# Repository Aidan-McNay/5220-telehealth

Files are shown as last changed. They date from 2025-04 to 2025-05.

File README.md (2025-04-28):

# 5220-telehealth

A repository of our design for MAE 5220: Introduction to IoT, which
obtains blood pressure data from an Omron Evolv BP7000, and transmits
it over LoRaWAN to The Things Network (TTN).

Unlike the code for the rest of the class, our target platform is a
Raspberry Pi Pico W, so the build process is different than labs.

## Repository Structure

 - **CMakeLists.txt**: Instructions for our CMake-based build system
 - **app**: Target applications for the Pico W (each with a `main`)
 - **ble**: Source code for interfacing over BLE
 - **cmake**: Extra CMake utilities
 - **lorawan**: Source code for interfacing over LoRaWAN
 - **lorawan-library-for-pico**: A submodule library for using LoRaWAN on the Pico W
 - **pcb**: Our PCB design for the system
 - **pico_sdk_import.cmake**: CMake support for the Raspberry Pi SDK
 - **ui**: Source code for interfacing with physical UI devices (LEDs, buttons, etc.)
 - **utils**: Utility code used throughout the project

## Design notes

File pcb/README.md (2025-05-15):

# pcb

PCB design. The files marked with "original" show the PCB that we ordered with the PMOS footprint mismatch as described in our report.

The current layout and schematic contain the updated PCB with the mismatch fixed. To produce the current PCB, use corrected_gerberdrill.zip when ordering from JLBPCB.

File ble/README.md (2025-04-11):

# ble

Software for connecting to the OMRON blood pressure sensor over Bluetooth Low Energy (BLE)

*(Note: Much of the code was adapted from ECE 4760's example [here](https://vanhunteradams.com/Pico/BLE/GATT_Client.html))*

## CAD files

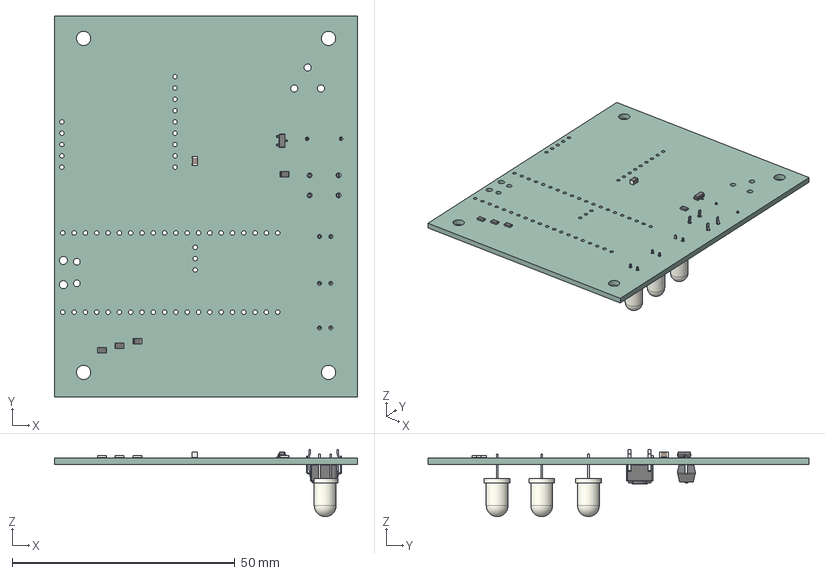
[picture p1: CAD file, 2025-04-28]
pcb/blood_pressure.step
68.0 x 85.5 x 15.1 mm
R_0805_2012Metric x 4
C_0805_2012Metric
SOT-23
LED_D5.0mm_Clear x 3
SW_PUSH_6mm
SW_DIP_SPSTx01_Slide_6.7x4.1mm_W7.62mm_P2.54mm_LowProfile
blood_pressure_PCB

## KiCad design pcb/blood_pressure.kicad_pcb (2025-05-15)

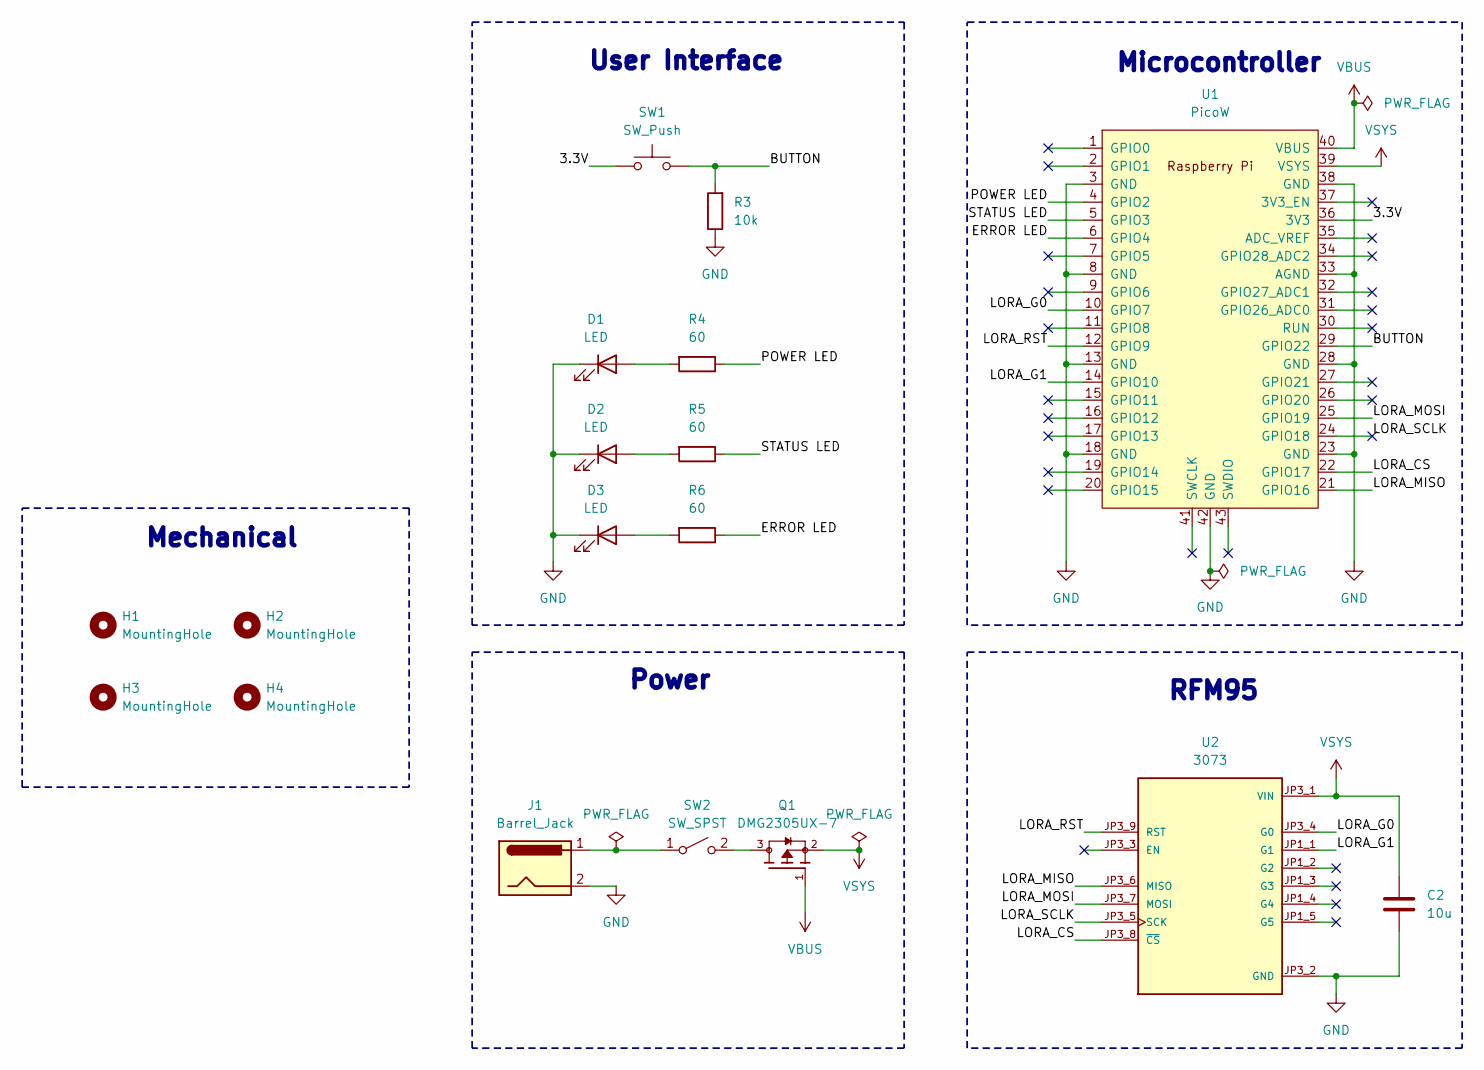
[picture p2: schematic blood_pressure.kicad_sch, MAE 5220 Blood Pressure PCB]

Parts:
C2: 10u; C_0805_2012Metric
D1, D2, D3: LED; LED_D5.0mm_Clear
H1, H2, H3, H4: MountingHole; MountingHole_3.2mm_M3
J1: Barrel_Jack; BarrelJack_CUI_PJ-102AH_Horizontal
Q1: DMG2305UX-7; SOT91P240X110-3N_DMG2305UX-7; PARTREV 09/2018
R3: 10k; R_0805_2012Metric
R4, R5, R6: 60; R_0805_2012Metric
SW1: SW_Push; SW_PUSH_6mm
SW2: SW_SPST; SW_DIP_SPSTx01_Slide_6.7x4.1mm_W7.62mm_P2.54mm_LowProfile
U1: PicoW; RPi_PicoW_SMD_TH
U2: 3073; rfm; PARTREV 2023-10-24

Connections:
/3.3V: SW1.1, U1.36 (3V3)
/BUTTON: R3.2, SW1.2, U1.29 (GPIO22)
/ERROR LED: R6.1, U1.6 (GPIO4)
/LORA_CS: U1.22 (GPIO17), U2.JP3_8 (~CS)
/LORA_G0: U1.10 (GPIO7), U2.JP3_4 (G0)
/LORA_G1: U1.14 (GPIO10), U2.JP1_1 (G1)
/LORA_MISO: U1.21 (GPIO16), U2.JP3_6 (MISO)
/LORA_MOSI: U1.25 (GPIO19), U2.JP3_7 (MOSI)
/LORA_RST: U1.12 (GPIO9), U2.JP3_9 (RST)
/LORA_SCLK: U1.24 (GPIO18), U2.JP3_5 (SCK)
/POWER LED: R4.1, U1.4 (GPIO2)
/STATUS LED: R5.1, U1.5 (GPIO3)
GND: C2.2, D1.1 (K), D2.1 (K), D3.1 (K), J1.2, R3.1, U1.3 (GND), U1.8 (GND), U1.13 (GND), U1.18 (GND), U1.23 (GND), U1.28 (GND), U1.33 (AGND), U1.38 (GND), U1.42 (GND), U2.JP3_2 (GND)
unnamed: D1.2 (A), R4.2
unnamed: D2.2 (A), R5.2
unnamed: D3.2 (A), R6.2
unnamed: J1.1, SW2.1 (A)
unnamed: Q1.3, SW2.2 (B)
VBUS: Q1.1, U1.40 (VBUS)
VSYS: C2.1, Q1.2, U1.39 (VSYS), U2.JP3_1 (VIN)

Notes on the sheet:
Microcontroller
RFM95
User Interface
Mechanical
Power

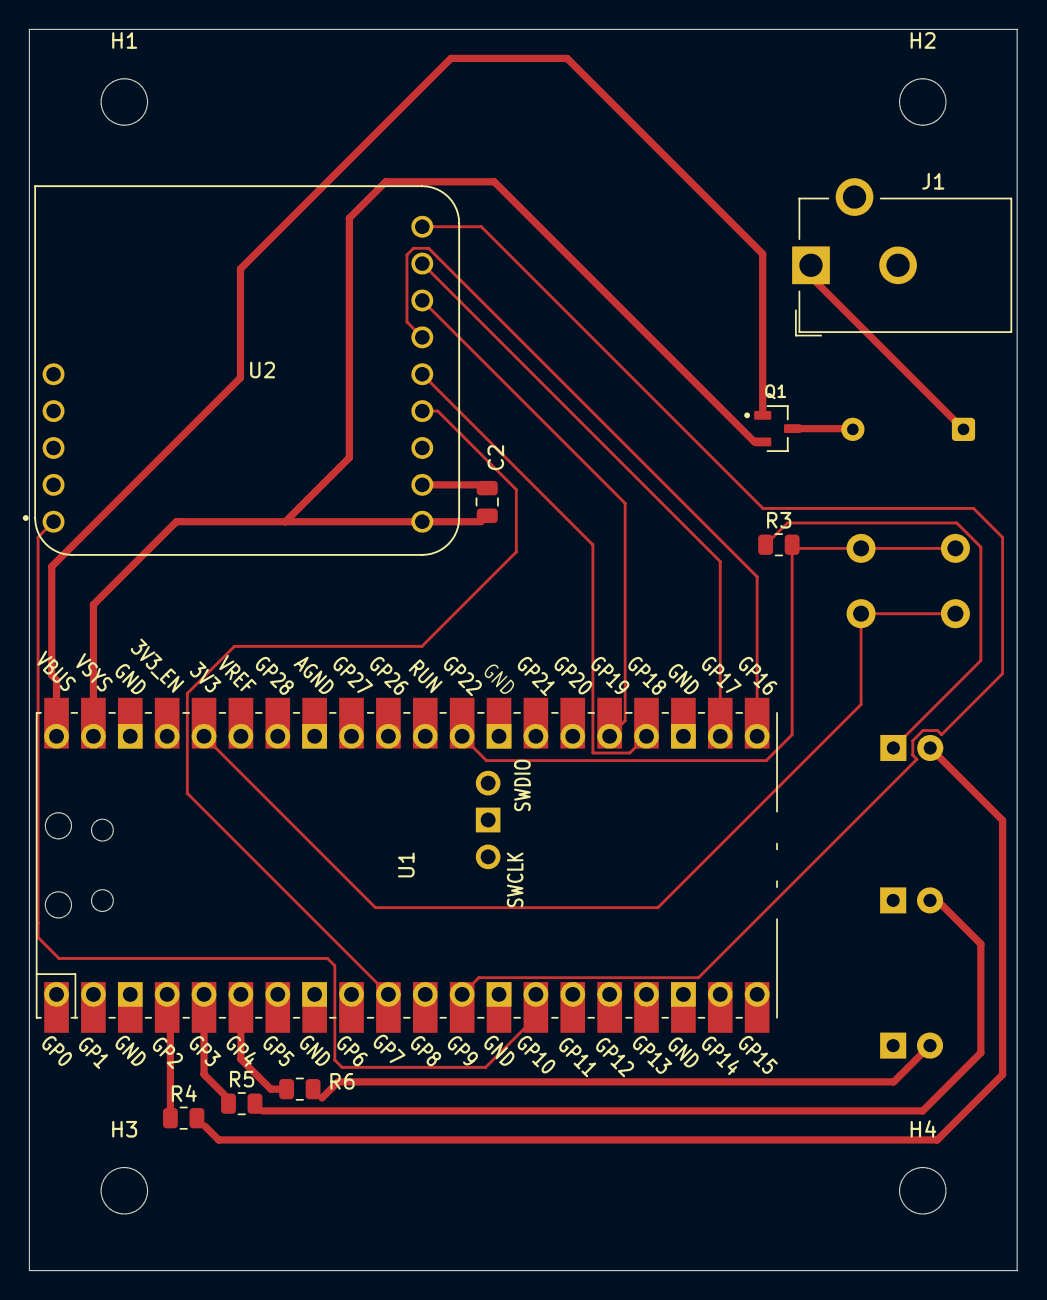
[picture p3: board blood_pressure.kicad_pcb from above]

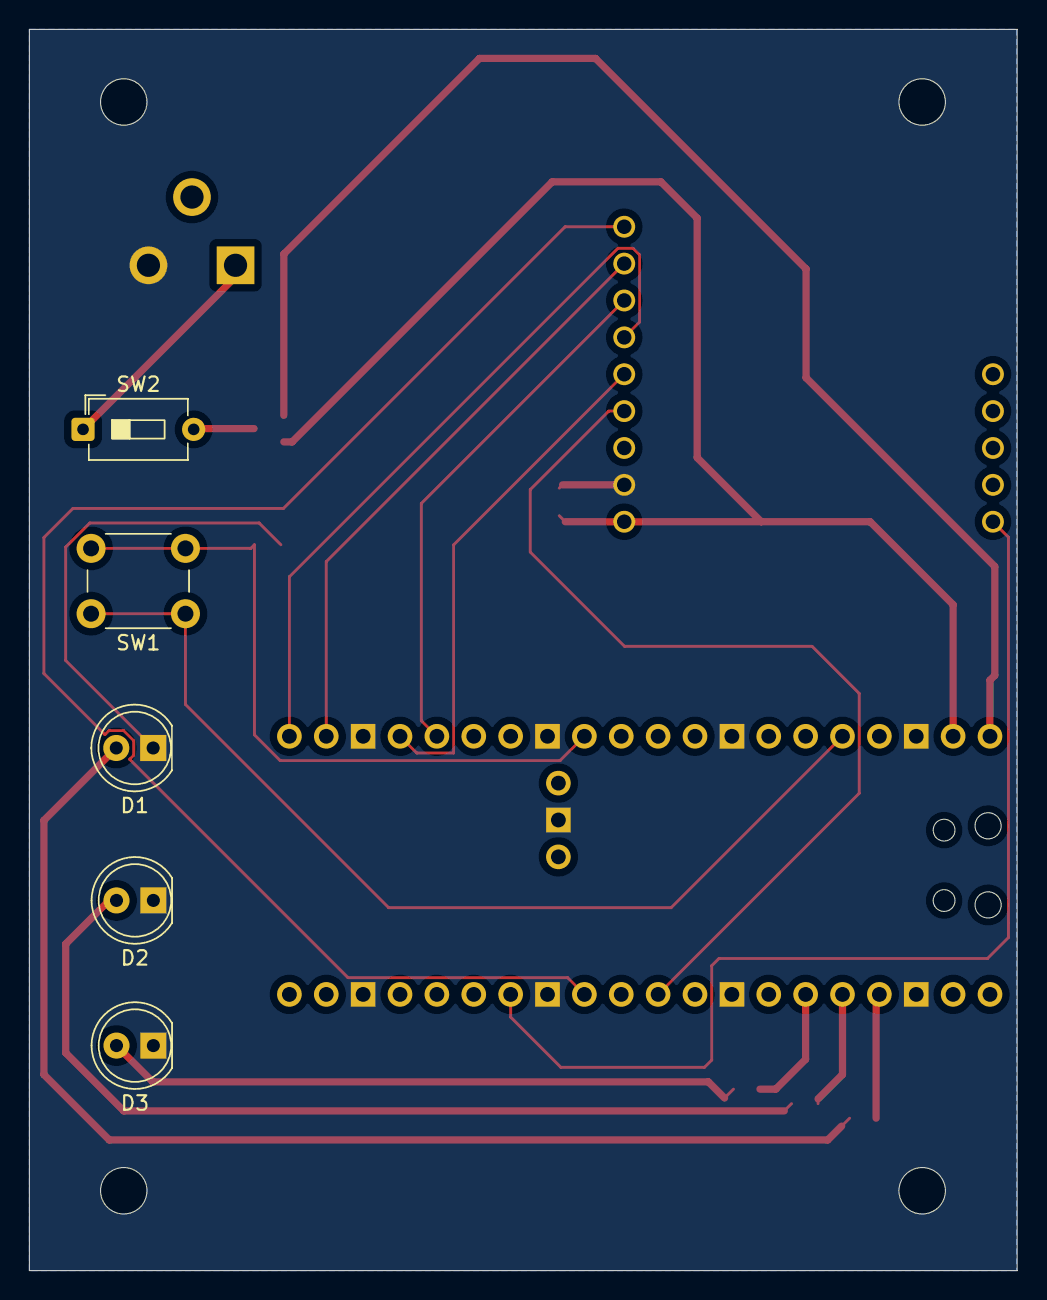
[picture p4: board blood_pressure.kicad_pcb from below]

Board: 4 copper layers, 68.0 x 85.5 mm, 18 parts (5 on the bottom side), 20 nets.

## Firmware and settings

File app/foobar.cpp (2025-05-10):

// =======================================================================
// foobar.cpp
// =======================================================================
// The top-level application for gathering and sending blood pressure
// data

#include "ui/state_machine.h"
#include "utils/pt_cornell_rp2040_v1.h"
#include <stdio.h>

#define BUTTON_GPIO 22
#define POWER_GPIO 2
#define STATUS_GPIO 3
#define ERROR_GPIO 4

FSM top( BUTTON_GPIO, STATUS_GPIO, ERROR_GPIO, POWER_GPIO );

static PT_THREAD( update_fsm( struct pt *pt ) )
{
  PT_BEGIN( pt );

  // Wait until discovered
  while ( 1 ) {
    top.update();
    lorawan_process_timeout_ms( 10 );
  }

  PT_END( pt )
}

int main( void )
{
  stdio_init_all();
  // Delay a bit to set up printf connection
  sleep_ms( 10000 );

#ifdef DEBUG
  lorawan_debug( true );
#endif

  printf( "Telehealth Communication\n" );

  pt_add_thread( update_fsm );
  pt_schedule_start;
}

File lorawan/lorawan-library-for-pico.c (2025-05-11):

/*!
 * \file      lorawan.c
 *
 * \brief     Implements the LoRaMac layer handling.
 *            Provides the possibility to register applicative packages.
 *
 * \remark    This file is based on
 *            https://github.com/Lora-net/LoRaMac-node/blob/master/src/apps/LoRaMac/periodic-uplink-lpp/B-L072Z-LRWAN1/main.c
 *
 *            Minor changes made from the `lorawan-library-for-pico`
 * implementation to support indications on confirmation
 *
 * \copyright Revised BSD License, see section \ref LICENSE.
 *
 * \code
 *                ______                              _
 *               / _____)             _              | |
 *              ( (____  _____ ____ _| |_ _____  ____| |__
 *               \____ \| ___ |    (_   _) ___ |/ ___)  _ \
 *               _____) ) ____| | | || |_| ____( (___| | | |
 *              (______/|_____)_|_|_| \__)_____)\____)_| |_|
 *              (C)2013-2018 Semtech
 *
 * \endcode
 *
 * \author    Miguel Luis ( Semtech )
 *
 */

#include "../../periodic-uplink-lpp/firmwareVersion.h"
#include "Commissioning.h"
#include "LmHandler.h"
#include "LmHandlerMsgDisplay.h"
#include "LmhpCompliance.h"
#include "NvmDataMgmt.h"
#include "RegionCommon.h"
#include "board.h"
#include "confirm.h"
#include "pico/lorawan.h"
#include "pico/time.h"
#include "rtc-board.h"
#include "sx1276-board.h"
#include <stdio.h>
#include <string.h>

/*!
 * LoRaWAN default end-device class
 */
#define LORAWAN_DEFAULT_CLASS CLASS_A

/*!
 * LoRaWAN Adaptive Data Rate
 *
 * \remark Please note that when ADR is enabled the end-device should be
 * static
 */
#define LORAWAN_ADR_STATE LORAMAC_HANDLER_ADR_ON

/*!
 * Default datarate
 *
 * \remark Please note that LORAWAN_DEFAULT_DATARATE is used only when ADR
 * is disabled
 */
#define LORAWAN_DEFAULT_DATARATE DR_0

/*!
 * LoRaWAN confirmed messages
 */
#define LORAWAN_DEFAULT_CONFIRMED_MSG_STATE \
  LORAMAC_HANDLER_UNCONFIRMED_MSG

/*!
 * User application data buffer size
 */
#define LORAWAN_APP_DATA_BUFFER_MAX_SIZE 242

/*!
 * LoRaWAN ETSI duty cycle control enable/disable
 *
 * \remark Please note that ETSI mandates duty cycled transmissions. Use
 * only for test purposes
 */
#define LORAWAN_DUTYCYCLE_ON true

/*!
 * Indicates if the end-device is to be connected to a private or public
 * network
 */
#define LORAWAN_PUBLIC_NETWORK true

/*!
 * User application data
 */
static uint8_t AppDataBuffer[LORAWAN_APP_DATA_BUFFER_MAX_SIZE];

/*!
 * User application data structure
 */
static LmHandlerAppData_t AppData = {
    .Buffer     = AppDataBuffer,
    .BufferSize = 0,
    .Port       = 0,
};

static void OnMacProcessNotify( void );
static void OnNvmDataChange( LmHandlerNvmContextStates_t state,
                             uint16_t                    size );
static void OnNetworkParametersChange( CommissioningParams_t* params );
static void OnMacMcpsRequest( LoRaMacStatus_t status, McpsReq_t* mcpsReq,
                              TimerTime_t nextTxIn );
static void OnMacMlmeRequest( LoRaMacStatus_t status, MlmeReq_t* mlmeReq,
                              TimerTime_t nextTxIn );
static void OnJoinRequest( LmHandlerJoinParams_t* params );
static void OnTxData( LmHandlerTxParams_t* params );
static void OnRxData( LmHandlerAppData_t*  appData,
                      LmHandlerRxParams_t* params );
static void OnClassChange( DeviceClass_t deviceClass );
static void OnBeaconStatusChange( LoRaMacHandlerBeaconParams_t* params );
#if ( LMH_SYS_TIME_UPDATE_NEW_API == 1 )
static void OnSysTimeUpdate( bool    isSynchronized,
                             int32_t timeCorrection );
#else
static void OnSysTimeUpdate( void );
#endif

static void OnTxPeriodicityChanged( uint32_t periodicity );
static void OnTxFrameCtrlChanged( LmHandlerMsgTypes_t isTxConfirmed );
static void OnPingSlotPeriodicityChanged( uint8_t pingSlotPeriodicity );

static LmHandlerCallbacks_t LmHandlerCallbacks = {
    .GetBatteryLevel           = BoardGetBatteryLevel,
    .GetTemperature            = NULL,
    .GetRandomSeed             = BoardGetRandomSeed,
    .OnMacProcess              = OnMacProcessNotify,
    .OnNvmDataChange           = OnNvmDataChange,
    .OnNetworkParametersChange = OnNetworkParametersChange,
    .OnMacMcpsRequest          = OnMacMcpsRequest,
    .OnMacMlmeRequest          = OnMacMlmeRequest,
    .OnJoinRequest             = OnJoinRequest,
    .OnTxData                  = OnTxData,
    .OnRxData                  = OnRxData,
    .OnClassChange             = OnClassChange,
    .OnBeaconStatusChange      = OnBeaconStatusChange,
    .OnSysTimeUpdate           = OnSysTimeUpdate,
};

static LmHandlerParams_t LmHandlerParams = {
    .Region              = ACTIVE_REGION,
    .AdrEnable           = LORAWAN_ADR_STATE,
    .IsTxConfirmed       = LORAWAN_DEFAULT_CONFIRMED_MSG_STATE,
    .TxDatarate          = LORAWAN_DEFAULT_DATARATE,
    .PublicNetworkEnable = LORAWAN_PUBLIC_NETWORK,
    .DutyCycleEnabled    = LORAWAN_DUTYCYCLE_ON,
    .DataBufferMaxSize   = LORAWAN_APP_DATA_BUFFER_MAX_SIZE,
    .DataBuffer          = AppDataBuffer,
    .PingSlotPeriodicity = REGION_COMMON_DEFAULT_PING_SLOT_PERIODICITY,
};

static LmhpComplianceParams_t LmhpComplianceParams = {
    .FwVersion.Value              = FIRMWARE_VERSION,
    .OnTxPeriodicityChanged       = OnTxPeriodicityChanged,
    .OnTxFrameCtrlChanged         = OnTxFrameCtrlChanged,
    .OnPingSlotPeriodicityChanged = OnPingSlotPeriodicityChanged,
};

/*!
 * Indicates if LoRaMacProcess call is pending.
 *
 * \warning If variable is equal to 0 then the MCU can be set in low power
 * mode
 */
static volatile uint8_t IsMacProcessPending = 0;

static volatile uint32_t TxPeriodicity = 0;

static const struct lorawan_abp_settings* AbpSettings = NULL;

static const struct lorawan_otaa_settings* OtaaSettings = NULL;

static uint8_t AppRxDataBuffer[LORAWAN_APP_DATA_BUFFER_MAX_SIZE];

static LmHandlerAppData_t AppRxData = {
    .Buffer     = AppRxDataBuffer,
    .BufferSize = 0,
    .Port       = 0,
};

static bool Debug = false;

extern void    EepromMcuInit();
extern uint8_t EepromMcuFlush();

const char* lorawan_default_dev_eui( char* dev_eui )
{
  uint8_t boardId[8];

  BoardGetUniqueId( boardId );

  sprintf( dev_eui, "%02X%02X%02X%02X%02X%02X%02X%02X", boardId[0],
           boardId[1], boardId[2], boardId[3], boardId[4], boardId[5],
           boardId[6], boardId[7] );

  return dev_eui;
}
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

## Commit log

2025-04-09 Initial PCB
    [blood_pressure.kicad_pcb, blood_pressure.kicad_sch]
2025-04-09 Working on BLE, button boilerplate
2025-04-12 Print UUID128 (still need to enable multiple services
2025-04-16 Final schematic
    [blood_pressure.kicad_sch]
2025-04-17 Final PCB
    [blood_pressure.kicad_pcb, blood_pressure.kicad_sch]
2025-04-27 Blood pressure successfully off device
2025-04-27 Fix printing
2025-04-27 Add arterial pressure
2025-05-09 Encryption code
    [bp_log.csv]
2025-05-10 Python code
    [bp_log.csv]
2025-05-11 state machine fixing interface
    [state_machine.cpp]
2025-05-11 Revert, factor out key
    [state_machine.cpp]
2025-05-11 process2.py and process3.py
    process2 dumps raw unparsed data into txt file and works. process3 is going to parsed into csv file
    [blood_pressure-B_Cu.gbl, blood_pressure-B_Mask.gbs, blood_pressure-B_Paste.gbp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]
2025-05-11 process3.py works
    [myData.csv]
2025-05-15 Read Me Files
    [blood_pressure-B_Cu.gbl, blood_pressure-B_Mask.gbs, blood_pressure-B_Paste.gbp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]
